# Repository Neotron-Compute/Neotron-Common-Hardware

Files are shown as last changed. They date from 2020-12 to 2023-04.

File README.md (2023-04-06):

# Neotron-Common-Hardware

Contains KiCad footprints and symbols shared across multiple Neotron projects. It also contains example schematics for circuits we expect to see on most Neotron boards.

## Components

### Audio Codec

* Texas Instruments TLV320AIC23B
  * I²S + I²C interface
  * Amplified 32mW headphone output and line out
  * Microphone in and line in
  * TSSOP-28 package (0.635mm pitch)
* Triple 3.5mm TRS jack (Kycon STX-4335-5BGP-S1)
  * Headphone Out (green)
  * Line In (blue)
  * Microphone In (pink)
* AC'97 Pin Header
  * Headphone Out
  * Microphone In
* Extra line-level output pin header (e.g. for additional RCA audio jacks - operates in addition to 3.5mm headphone jack output)
* Internal line-level input pin header (e.g. for CD-ROM audio - disabled when line-in 3.5mm jack in-use)

### Super VGA output

* 15-pin D-Sub VGA interface
* 18-bit (6-6-6) and 12-bit (4-4-4) RGB R2R DACs
  * Requires you to connect up a CPU that can generate digital parallel RGB video
* 3peak TPF133A or Texas Instruments THS7316 RGB video buffer
   * 36 MHz bandwidth - 1024x768@60Hz maximum
   * 6dB gain
   * Drives 75 ohm standard VGA interface
   * SOIC-8 package (1.27mm pitch)
* Texas Instruments TPD7S019 Sync/DDC level shifter and RGB EMC filter
   * SSOP-16 package (0.635mm pitch)

### RS232 Interface

* Tx, Rx, RTS and CTS signals
* 3.3V TTL on the MCU side
* Low-power ST ST3232C RS-232 level shifter (powered from single 3.3V rail)
* RS-232 signalling on a 9-pin D-Sub connector (or 10-pin IDC box header), wired DTE

### USB

* Four port USB 2.0 High Speed hub
* MaxLinear XR22404CG28 USB2.0 hub IC
  * SSOP-28 package (0.635mm pitch)
* Two USB 2.0 High Speed Type-A ports
* 8-pin PC case style USB pin-header (providing two USB 2.0 High Speed ports)
* Each port limited to 500mA with over-current protection

### Ethernet

* 10/100base-T Ethernet
* Microchip ENC424J600 Ethernet MAC/PHY with SPI connection to main CPU
  * TQFP-44 package (0.8mm pitch)
* Link and Activity LEDs

### Board Management Controller

Power-on Reset sequencing, soft shutdown, voltage monitoring and PS/2 interfacing is handled by a separate STM32F0 SoC.

* ST Micro STM32F0 (STM32F030K6T6) microcontroller
  * 32-bit Arm Cortex-M0+ Core
  * 3.3V I/O (5V tolerant)
  * 32 KiB Flash
  * 4 KiB SRAM
  * LQFP-32 package (0.8mm pitch)
* Controls two PS/2 ports
* Monitors 5V and 3.3V rails
* Controls system reset, soft-on and soft-off for main CPU
* Can the main 5V regulator on and off
* Runs from 3.3V stand-by regulator
* SPI interface (with dedicated IRQ line) with main CPU
* Secondary I²C bus which can be controlled over SPI

| Pin  | Name | Signal | Function |
| :--- | :--- | :--- | :--- |
| 02 | PF0  | nBUTTON_PWR | Power Button Input (active low) |
| 03 | PF1  | nBUTTON_RST | Reset Button Input (active low) |
| 06 | PA0  | MON_3V3 | 3.3V rail monitor Input (1.65V nominal) |
| 07 | PA1  | MON_5V | 5.0V rail monitor Input (1.65V nominal) |
| 08 | PA2  | nSYS_RESET  | Reset Output to reset the rest of the system |
| 09 | PA3  | DC_ON | PSU Enable Output |
| 10 | PA4  | SPI1_NSS | SPI Chip Select Input (active low) |
| 11 | PA5  | SPI1_SCK | SPI Clock Input |
| 12 | PA6  | SPI1_CIPO | SPI Data Output |
| 13 | PA7  | SPI1_COPI | SPI Data Input |
| 14 | PB0  | LED0 | PWM output for first Status LED |
| 15 | PB1  | LED1 | PWM output for second Status LED |
| 18 | PA8  | nHOST_IRQ | Interrupt Output to the Host (active low) |
| 19 | PA9  | USART1_TX | UART Transmit Output |
| 20 | PA10 | USART1_RX | UART Receive Input |
| 21 | PA11 | USART1_CTS  | UART Clear-to-Send Output |
| 22 | PA12 | USART1_RTS  | UART Ready-to-Receive Input |
| 23 | PA13 | SWDIO | SWD Progamming Data Input |
| 24 | PA14 | SWCLK | SWD Programming Clock Input |
| 25 | PA15 | PS2_CLK0 | Keyboard Clock Input |
| 26 | PB3  | PS2_CLK1 | Mouse Clock Input |
| 27 | PB4  | PS2_DAT0 | Keyboard Data Input |
| 28 | PB5  | PS2_DAT1 | Mouse Data Input |
| 29 | PB6  | I2C1_SCL | I²C Clock |
| 30 | PB7  | I2C1_SDA | I²C Data |

Note that in the above table, the UART signals labelled from the point of view of the BMC chip (i.e. UART_RX is an input to the BMC). The PS/2 signals are 5V open-collector, and so must be on 5V tolerant pins. Everything else runs at 3.3V.

This design should also be pin-compatible with the following SoCs (although the software may need recompiling with a different _Peripheral Access Crate_):

* STM32F031K6Tx
* STM32F042K4Tx
* STM32F042K6Tx
* STM32F051K4Tx
* STM32F051K6Tx
* STM32F051K8Tx
* STM32L071KBTx
* STM32L071KZTx
* STM32L072KZTx
* STM32L081KZTx
* STM32L082KZTx

Note that not all STM32 pins are 5V-tolerant, and as noted above, the PS/2 pins are 5V open-collector. You must therefore ensure that whichever part you pick has 5V-tolerant pins (marked `FT` or `FTt` in the datasheet) for the PS/2 signals. All of the parts above _should_ be OK, but they haven't been tested. Let us know if you try one!

### PS/2 Keyboard and Mouse

* Kycon two-port stacked 6-pin DIN sockets (Kycon KMDGX-6S/6S-S4N)
* Controlled via Board Management Controller

### Power Supply

* Unregulated 12V (8V to 28V) input fused with a PTC at 2A
* 3A 5.0V main regulator (DC-DC switch-mode regulator module)
  * Morsun K7805-3AR3
* 30mA 3.3V stand-by regulator (a micropower linear regulator)
* 1A 3.3V regulator (a high-power 1117 type linear regulator)
* Controlled by the Board Management Controller

### CPU Socket

The CPU can either be designed to solder direct to your particular motherboard design, or it can be fitted to a second PCB 'CPU card' which plugs into a socket on the motherboard. We have designed a special 80-pin socket pinout, which provides all the signals for required for the standard peripherals available in this design.

The socket is basically two 2x20 pin headers, placed 130 mil apart. This should give enough space to fit even a TQFP-176 microcontroller and some TSOP-54 SDRAM.

The pins are labelled in row.column fashion, i.e. 1.1 is top left, 1.20 is top right and 4.20 is bottom right.

```
 +----- Pin 1.1
 |
 v
+---------------------------------------+
|o o o o o o o o o o o o o o o o o o o o|
|o o o o o o o o o o o o o o o o o o o o|
+---------------------------------------+

+---------------------------------------+
|o o o o o o o o o o o o o o o o o o o o|
|o o o o o o o o o o o o o o o o o o o o|
+---------------------------------------+
                                       ^
                                       |
                         Pin 4.20 -----+
```

| Pin  | Function |
| :--- | :--- |
| 1.1  | VGA_RED5 |
| 1.2  | VGA_RED4 |
| 1.3  | VGA_RED3 |
| 1.4  | VGA_RED2 |
| 1.5  | VGA_RED1 |
| 1.6  | VGA_RED0 |
| 1.7  | VGA_GREEN5 |
| 1.8  | VGA_GREEN4 |
| 1.9  | VGA_GREEN3 |
| 1.10 | VGA_GREEN2 |
| 1.11 | VGA_GREEN1 |
| 1.12 | VGA_GREEN0 |
| 1.13 | VGA_BLUE5 |
| 1.14 | VGA_BLUE4 |
| 1.15 | VGA_BLUE3 |
| 1.16 | VGA_BLUE2 |
| 1.17 | VGA_BLUE1 |
| 1.18 | VGA_BLUE0 |
| 1.19 | VGA_HSYNC |
| 1.20 | VGA_VSYNC |
| 2.1  | VGA_DDC_SDA |
| 2.2  | VGA_DDC_SCL |
| 2.3  | UART_RX |
| 2.4  | UART_TX |
| 2.7  | 3V3 |
| 2.8  | 3V3 |
| 2.9  | 3V3 |
| 2.10 | GND |
| 2.11 | GND |
| 2.12 | GND |
| 2.13 | AUDIO_BCLK_TO_CODEC  |
| 2.14 | AUDIO_DAT_TO_CODEC |
| 2.15 | AUDIO_LR_TO_CODEC |
| 2.16 | AUDIO_DAT_FROM_CODEC |
| 2.17 | AUDIO_LR_FROM_CODEC  |
| 2.18 | USB_EN |
| 2.19 | USB_D- |
| 2.20 | USB_D+ |
| 3.1  | I2C_SDA |
| 3.2  | I2C_SCL |
| 3.3  | UART_CTS |
| 3.4  | UART_RTS |
| 3.7  | GND |
| 3.8  | GND |
| 3.9  | GND |
| 3.10 | 5V |
| 3.11 | 5V |
| 3.12 | 5V |
| 3.13 | ~SPI_CS7 |
| 3.14 | ~SPI_CS6 |
| 3.15 | ~SPI_CS5 |
| 3.16 | ~SPI_CS4 |
| 3.17 | ~SPI_CS3 |
| 3.18 | ~SPI_CS2 |
| 3.19 | ~SPI_CS1 |
| 3.20 | ~SPI_CS0 |
| 4.1  | ~SDMMC_CARD_DETECT |
| 4.2  | ~SDMMC_WRITE_PROT |
| 4.3  | SDMMC_DAT2 |
| 4.4  | SDMMC_DAT3 |
| 4.5  | SDMMC_CMD |
| 4.6  | SDMMC_CLK |
| 4.7  | SDMMC_DAT0 |
| 4.8  | SDMMC_DAT1 |
| 4.9  | SPI_COPI |
| 4.10 | SPI_CIPO |
| 4.11 | SPI_CLK |
| 4.12 | ~RESET |
| 4.13 | ~IRQ7 |
| 4.14 | ~IRQ6 |
| 4.15 | ~IRQ5 |
| 4.16 | ~IRQ4 |
| 4.17 | ~IRQ3 |
| 4.18 | ~IRQ2 |
| 4.19 | ~IRQ1 |
| 4.20 | ~IRQ0 |

## Expansion

The (up-to) seven expansion sockets allow you to add on I²C or SPI based devices at a later date. Each provides a single chip-select and a single IRQ line - the motherboard design should ensure each socket gets a unique signal for each of these. Each expansion device should also contain a AT24C256 or similar EEPROM device. To allow these EEPROM devices to be scanned, each slot also contains three `EEPROM_ADDRESS` pins, tied to Vcc or GND in a unique combination. These should be connected through to the EEPROM address lines on your AT24C256, thus ensuring that each expansion card has its EEPROM at a unique address - 0x50 on Slot 0 through to a maximum possible 0x57 for Slot 7. Where your board has on-board devices, you should fit an AT24C256 EEPROM for each device so that the on-board devices can be discovered, exactly as if they were on an expansion card.

The expansion slot is a simple 2x10 header. We suggest the use of a TE card-edge connector, but you could equally use two 1x10 pin-headers if desired.

The pin functions are:

```
     SPI_COPI   1    2   GND
     SPI_CIPO   3    4   GND
      SPI_CLK   5    6   GND
      ~SPI_CS   7    8   ~IRQ
      I2C_SDA   9   10   I2C_SCL
 EEPROM_ADDR0   11  12   EEPROM_ADDR1
 EEPROM_ADDR2   13  14   ~RESET
           5V   15  16   5V
          3V3   17  18   3V3
          GND   19  20   GND
```

There are symbols and footprints for the mainboard side (card-edge socket, supplies power), and the expansion card side (golden-finger edge connector, receives power).

## Expansion Ideas

Why not design and build your own expansion card? You could try designing:

* A dual Atari/SEGA 9-pin Joypad Interface
* A Mikro Eletronika Click adaptor, allow many of the range of [Click boards](https://www.mikroe.com/click) to be fitted
* A Wi-Fi/Bluetooth card, using an Espressif ESP32
* A second processor card - perhaps with a RISC-V microcontroller, or classic Zilog Z80
* An OPL2 or OPL3 based FM synthesiser card
* An ISA adaptor card (taking an ISA card at right-angles, i.e. parallel to the base board) - a simple microcontroller should be able to bit-bang the ISA bus at 8 MHz and offer an SPI peripheral interface to the Neotron Expansion Slot
* An IDE interface card, allowing 40-pin IDE Hard Disk Drives and CD-ROM drives to be used - this will be quite similar to an ISA bus adaptor
* A floppy drive controller card - either using an eSPI Super I/O chip, or connecting a legacy ISA bus floppy controller as per the ISA adaptor
* A video card for a second monitor output, perhaps based on the CPLD used in the [VGAtonic](https://hackaday.io/project/6309-vga-graphics-over-spi-and-serial-vgatonic)

## Changelog

See [CHANGELOG.md](./CHANGELOG.md) for a list of detailed changes.

## Git Setup

We recommend you have the following Git config set:

```
$ git config --global filter.kicad_project.clean "sed -E 's/^update=.*$/update=Date/'"
$ git config --global filter.kicad_project.smudge cat
$ git config --global filter.kicad_sch.clean "sed -E 's/#(PWR|FLG)[0-9]+/#\1?/'"
$ git config --global filter.kicad_sch.smudge cat
```

See https://jnavila.github.io/plotkicadsch/ for details.

## Automated Builds

This project treats a PCB like embedded firmware:

* The *source files* are the KiCAD 7 files (in `./Kicad`)
* The *compiler* is KiCAD 7, plus various automation plug-ins (like KiBom)
* The *build system* is [KiBot](https://github.com/INTI-CMNB/KiBot)
* The *build outputs* are PDF versions of the schematic and the PCB, plus various zipped Gerber and Drill files.

We do not check *build outputs* into this repository - *ever*. Instead, we run a Github Action which uses KiBot to generate our outputs. On a regular Pull Request, the *build outputs* are stored as *artefacts* against the particular Github Action run. When a new version is tagged, the *build outputs* are stored as files against a [Github Release](https://github.com/Neotron-Compute/Neotron-Common-Hardware/releases).

Of course, the PCB in this project isn't useful by itself - it's a starting point for your project. You should probably include this repo as a Git Submodule, and add the symbol library and footprint library to your own KiCAD project.

You can build locally using the KiBot docker container:

```console
~/Neotron-Common-Hardware $ docker run --rm -ti -v $(pwd):/work setsoft/kicad_auto:ki7
root@12345678:/# cd /work/Kicad
root@12345678:/work/Kicad# kibot -c docs.kibot.yml -e Neotron-Common-Hardware.kicad_sch -b Neotron-Common-Hardware.kicad_pcb -d docs
```

This will build everything and put it in the `./Kicad/docs` directory.

## Licence

This schematic and PCB design is Copyright (c) The Neotron Developers.



This work is licensed under a [Creative Commons Attribution-ShareAlike 4.0 International License](http://creativecommons.org/licenses/by-sa/4.0/).

## Contribution Agreement

Unless you explicitly state otherwise, any contribution intentionally submitted for inclusion in the work by you, as defined in the Apache-2.0 license, shall be licensed as above, without any additional terms or conditions.

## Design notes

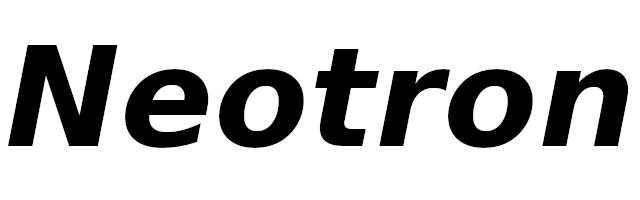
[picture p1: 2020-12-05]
neotron.png

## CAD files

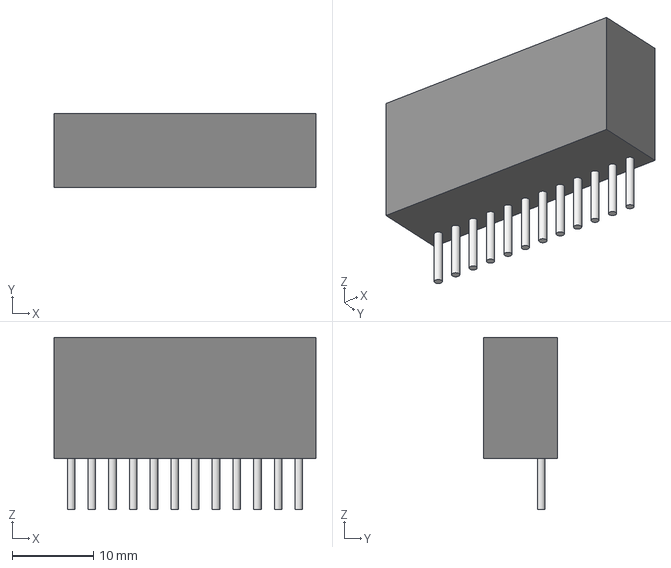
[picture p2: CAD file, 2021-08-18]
Kicad/Models/K78XX-3AR3.step
32.2 x 9.04 x 21.2 mm

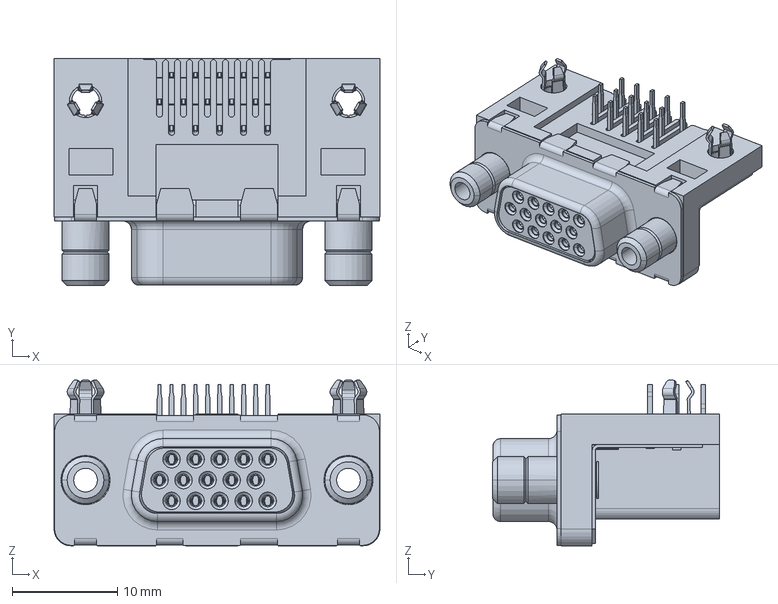
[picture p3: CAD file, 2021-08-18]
Kicad/Models/ICD15S13E4GV00LFc.stp
31.0 x 21.6 x 15.8 mm

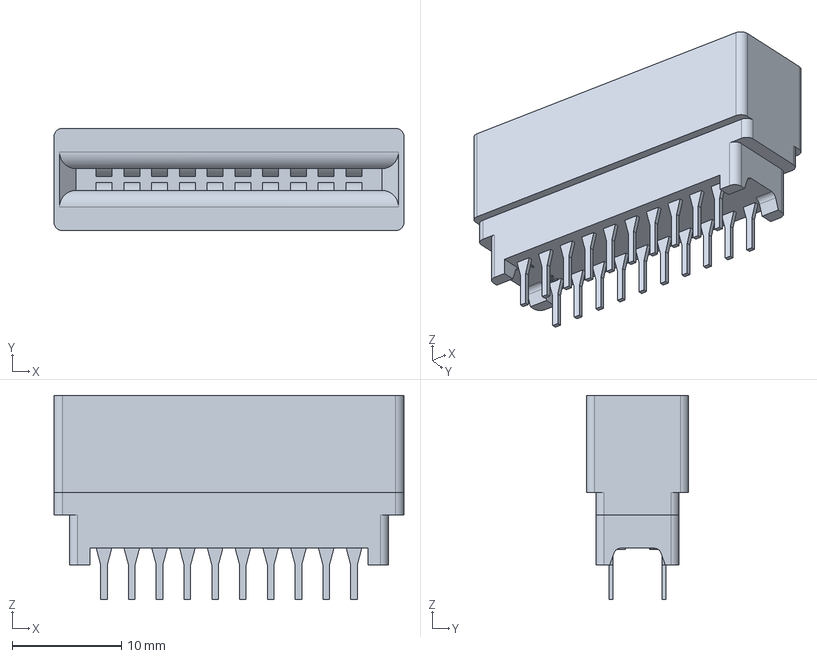
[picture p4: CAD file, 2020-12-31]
Kicad/Models/5-5530843-0--3DModel-STEP-1.STEP
32.0 x 9.35 x 18.7 mm

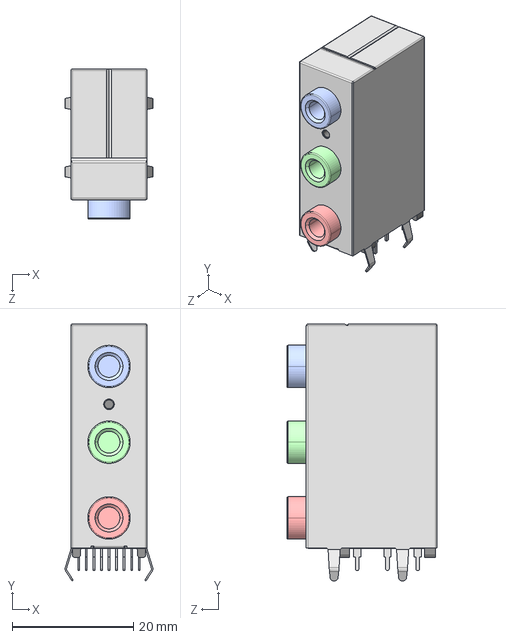
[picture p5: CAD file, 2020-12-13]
Kicad/Models/STX-4335-5BGP-S1_rB3.STEP
14.5 x 42.4 x 24.8 mm

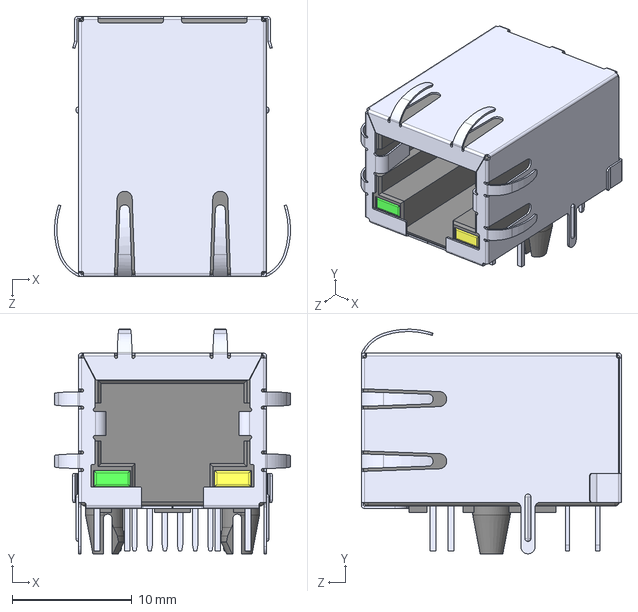
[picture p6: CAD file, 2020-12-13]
Kicad/Models/RJMG1BD3B8K1ANR--3DModel-STEP-56544.STEP
19.7 x 18.8 x 21.8 mm

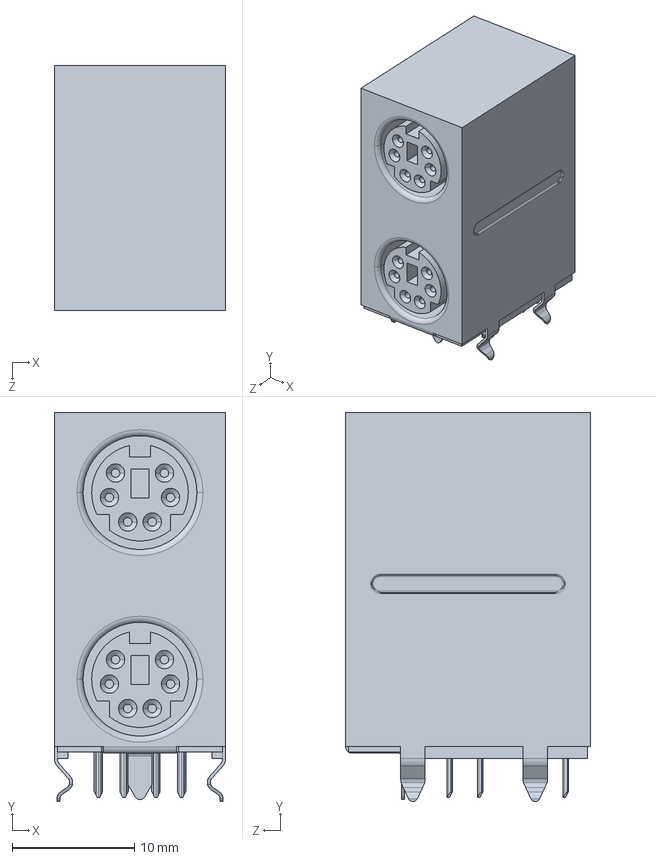
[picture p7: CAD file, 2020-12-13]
Kicad/Models/KMDGX-6S-6S-S4N_rB8.STEP
14.0 x 31.8 x 20.0 mm

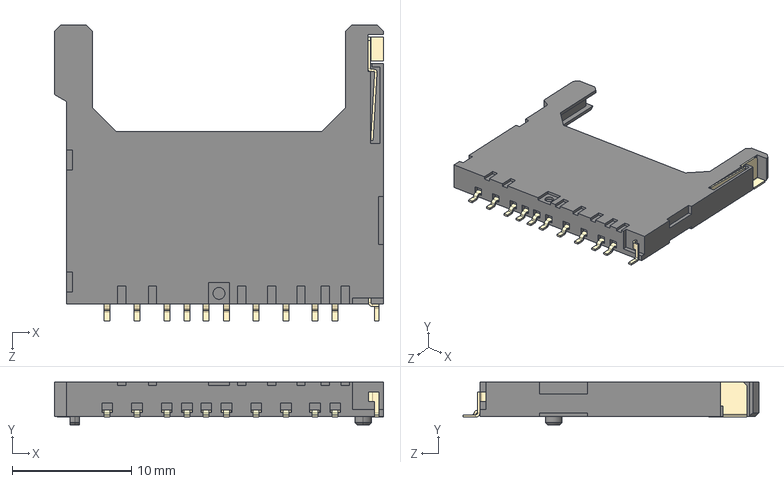
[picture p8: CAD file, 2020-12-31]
Kicad/Models/145638009211859+--3DModel-STEP-56544.STEP
27.6 x 3.60 x 24.8 mm

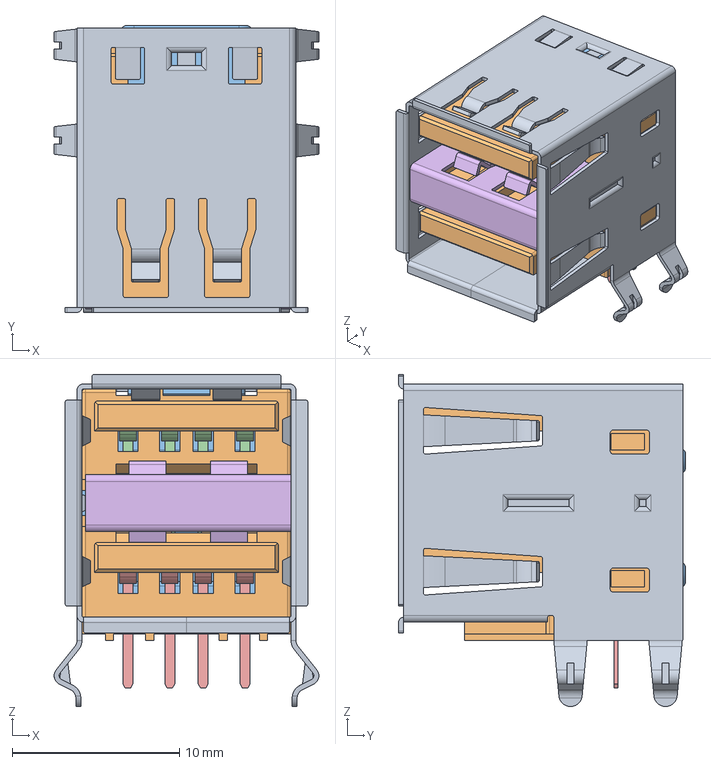
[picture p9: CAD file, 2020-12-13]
Kicad/Models/61400826021.stp
15.8 x 17.1 x 19.8 mm

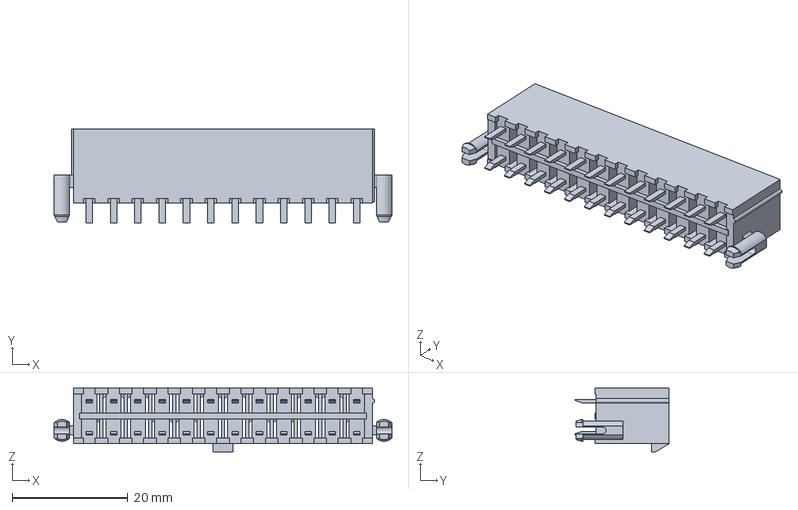
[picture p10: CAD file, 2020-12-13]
Kicad/Models/039299246.stp
58.4 x 16.3 x 11.0 mm

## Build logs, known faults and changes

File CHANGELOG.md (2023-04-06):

# Changelog

## Unreleased Changes

* None

## v2.0.0

* Updated to KiCAD 7
* Reduced size of holes for PSU pins from 1.2mm to 1.02mm

## v1.0.0

* Updated to KiCAD 6
* Backported changes from Neotron Pico
  * Split microphone audio / bias
  * DNF components now not shown on iBOM
  * External LED drive is 5V 20mA
  * Two PSU control BJTs are now surface mount
  * Use 200mA Holtek HT7533-1 stand-by regulator
  * Added internal 12V input header
  * K7805-3AR3 control pin is protected with a zener (allows higher input voltages)
  * HDD LED is driven from I/O mux, not BMC
  * Replaced 12 MHz Crystal with JLCPCB basic part
  * Replaced SD Card with Amphenol part
  * Replaced decoupling with single 10uF
  * Added PC speaker output
  * Changed K7805-3AR3 to have ceramic output cap
  * Increased VGA DAC current
  * Replace 74HC245 with 74HC138, plus five LEDS for the now spare pins
  * Adds 6mm switches for power and reset
  * Added internal 5V/3.3V output header
  * Reverse polarity protection on the input

## v0.12.0

* Add a second TPF133A but with RGB pins swapped (the channels are identical).

## v0.11.0

* Added Expansion Edge connector for making expansion cards.

## v0.10.0

* SYS_RESET is pulled down.
* 5V PSU's `Ctrl` input is now controlled with PNP/NPN transistor pair.
* Added extra explanatory text to BMC page
* Added not on audio sheet about split grounds.

## v0.9.3

* Remove audio split ground by joining GND and GNDA

## v0.9.2

* Change Audio LR and BCLK pins to be bi-directional
* Also renamed all Audio pins for clarity

## v0.9.1

* Swapped BUTTON_PWR and SYS_RESET to avoid DRC issue
* Split PSU and BMC into two separate sheets
* Swapped some pins on the STM32 to make it compatible with more alternatives

## v0.9.0

* Changed STM32 pinout to add 4-wire UART and move to SPI bus
* Added some Mouser part numbers
* Marked resistors as 1% where not specified

## v0.8.0

* Updated some 5V0 caps from 10V to 16V
* README updates

## v0.7.0

* Replaced STM32F0 TSSOP with LQFP-32
  * Has 0.8mm pitch (instead of 0.65mm) so should be easier to solder
* Replaced most of the big electrolytics with 0805 MLCC
  * Takes up less board space

## v0.6.0

* Added 3D model for USB header
* Changed main input Inductor to horizontal footprint
* Created footprint for Mornsun DC/DC PSU
* Added header for case power LED
* Changed BMC debug header to standard part

## v0.5.0

* Swap BMC from NXP KE04Z to ST STM32F0

## v0.4.0

* Added missing part numbers.

## v0.3.1

* Fix ERC error when SPI CIPO pins joined together.

## v0.3.0

* Added R2R DAC

## v0.2.0

* Added RTC sheet

## v0.1.0

First WIP draft release.

* Sub-modules added
* Connector fit in ATX IO area tested
* Audio Codec Sheet
* SD Card Sheet
* Ethernet Sheet
* Video Sheet
* Serial Sheet
* CPU Socket defined
* Expansion Socket defined

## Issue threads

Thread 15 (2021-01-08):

Create specific debug header

thejpster, 2021-01-08:
The STM32F0 currently has a combination of test points and jumpers. We should just use a 2x5 2.54mm pin header. and give the user instructions on where to fit the jumpers.

Closed 2021-01-08.

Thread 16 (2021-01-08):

Add LED header

thejpster, 2021-01-08:
The status LED that tells us the system is up and running is currently a 5mm LED. We should add a second 1k resistor and a 2.54mm pin header for a case LED. This should be located near the reset and power button headers.

thejpster, 2021-01-08:
Closed by #24

Closed 2021-01-08.

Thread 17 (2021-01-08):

Mornsun PSU needs its own footprint

thejpster, 2021-01-08:
The pins on the Mornsun PSU appear to be 3mm pitch not 2.54mm pitch. We should just draw ourselves a nice footprint for the PSU.

thejpster, 2021-01-08:
No, it its 2.54mm after all. I was comparing a physical unit with a 2.54mm pin header I had lying around - except it happened to be a 2mm pin header!

Anyway, made a new footprint with a courtyard and cleaned up the symbol pins.

Closed 2021-01-08.

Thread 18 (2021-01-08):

Inductor won't stand up

thejpster, 2021-01-08:
The legs on the big 22uH inductor are too short to allow it to stand vertically. We should swap to a horizontal footprint, or change the part.

Closed 2021-01-08.

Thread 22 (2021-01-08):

Consider DIN 41612 connectors

thejpster, 2021-01-08:
Edge connectors are inexpensive, but require your expansion cards to be hard gold if you want any kind of durability. This really puts up the price of the expansion PCBs.

Nubus used DIN 41612 connectors, which are rated for 50 to 500 insertions. Plus they look a) cool b) authentically retro.

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

thejpster, 2021-01-16:
This 48 pin, 3 row, vertical socket is nice:

https://www.te.com/commerce/DocumentDelivery/DDEController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

https://www.digikey.co.uk/product-detail/en/te-connectivity-amp-connectors/5536397-5/A113959-ND/3466293

Costs £2.29 in small quantities. I do think the baseboard should have sockets because it supplies power. The Raspberry Pi uses a pin header rather than a socket and I think it's too easy to touch 5V and GND together.

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

thejpster, 2021-01-16:
This right angle socket at £2.90 is the matching part.

https://www.digikey.co.uk/product-detail/en/te-connectivity-amp-connectors/5650478-5/A32298-ND/811088

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

thejpster, 2021-01-16:
If you just use "normal" 0.1" headers and sockets, it's much cheaper.

https://www.digikey.co.uk/product-detail/en/sullins-connector-solutions/SFH11-PBPC-D08-ST-BK/S9196-ND/1990089

68p in small qtys.

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

Closed 2021-06-18.

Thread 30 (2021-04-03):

CODEC LR and BCLK pins should be bi-dir

thejpster, 2021-04-03:
The BCLK pin and the two LRCLK pins are inputs in so-called _slave_ mode and outputs in so-called _master_ mode. The sheet should mark them as bi-dir.

thejpster, 2021-04-04:
Fixed in 6d5f5d06e4

Closed 2021-04-06.

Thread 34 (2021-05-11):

Switch to Octopart CPL

thejpster, 2021-05-11:
Octopart has a "common parts library", which part numbers for generic items (like resistors, capacitors, etc). In the Octopart BOM tool these will then map to a manufacturer specific equivalent.

https://octopart.com/common-parts-library

We should use parts from the CPL in this repo.

Closed 2021-06-18.

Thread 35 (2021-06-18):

Backport changes from Neotron Pico

thejpster, 2021-06-18:
Neotron Pico had to copy-paste the schematics due to Kicad issues.

We should pick up the changes and bring them back here.

Closed 2021-06-18.

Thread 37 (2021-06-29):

Expansion Card

thejpster, 2021-06-29:
We need a demonstration expansion card. Something with the gold fingers and holes for an expansion card bracket.

For brackets see:

* https://www.keyelco.com/category.cfm/Brackets-Computer-Mounting/Computer-Brackets-PC-Card/id/427
* https://www.aliexpress.com/item/32974251930.html
* https://www.mouser.co.uk/Electromechanical/Hardware/Circuit-Board-Hardware-PCB/_/N-5g2e

thejpster, 2021-08-20:
See https://github.com/Neotron-Compute/Neotron-Expansion-Template

Closed 2021-08-20.

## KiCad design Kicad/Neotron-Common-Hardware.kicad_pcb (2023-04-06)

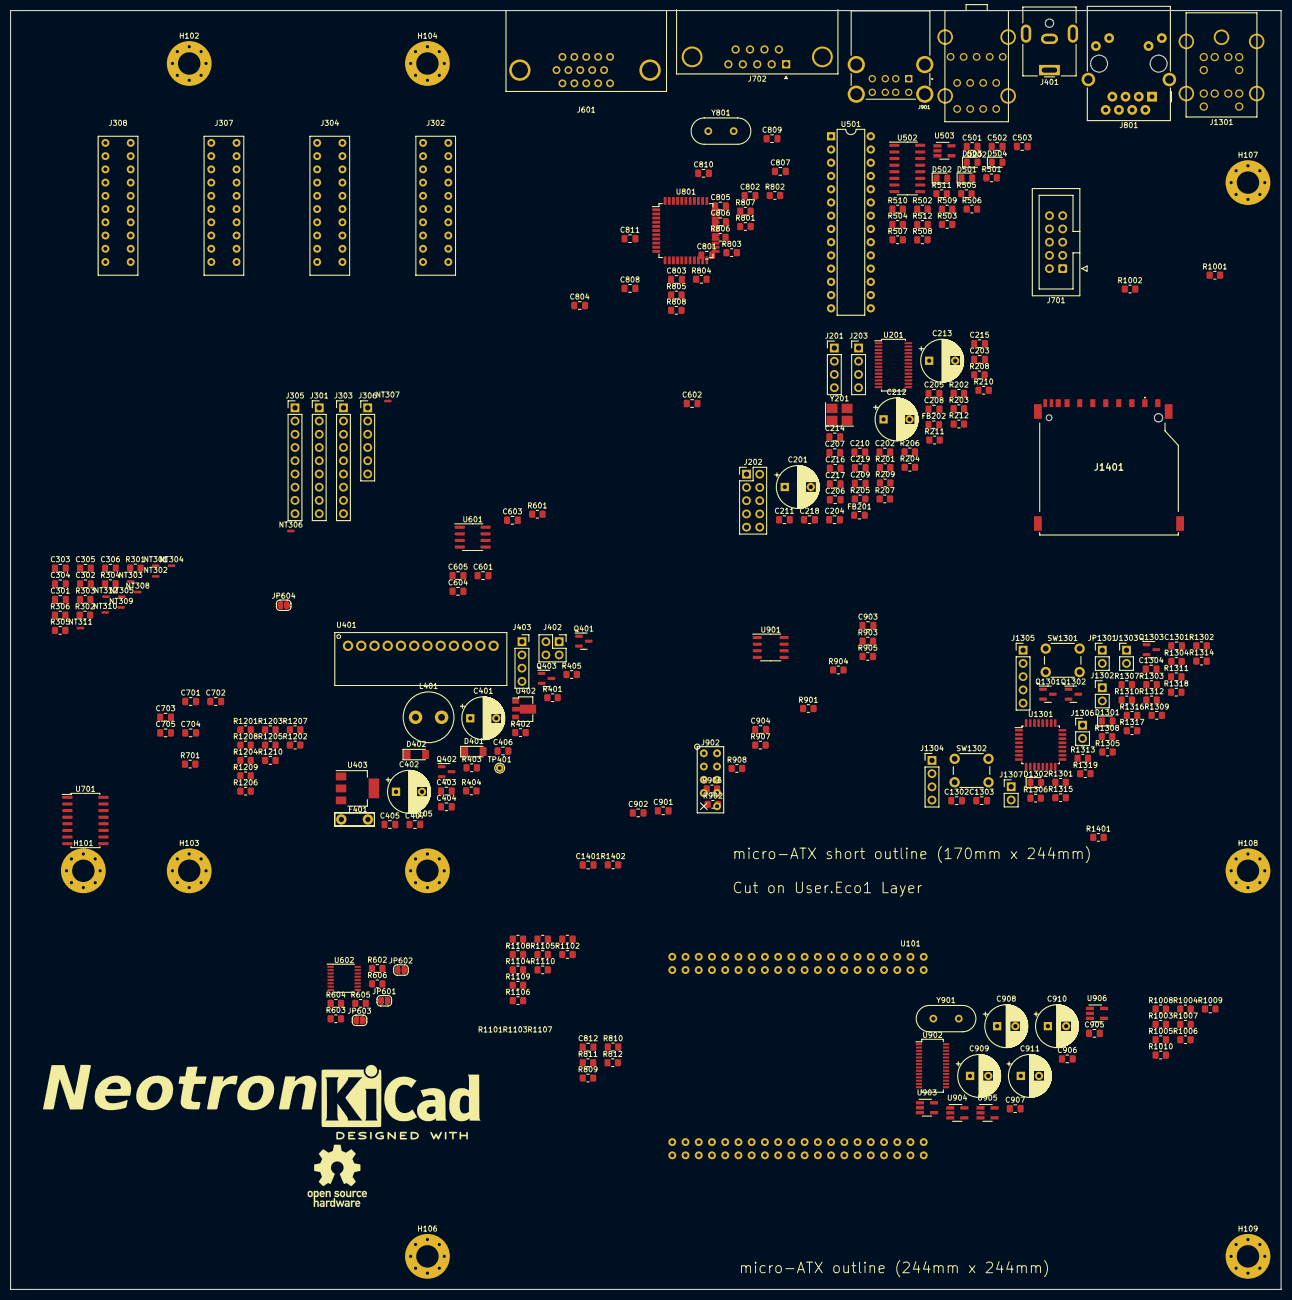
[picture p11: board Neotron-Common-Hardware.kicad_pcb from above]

Board: 4 copper layers, 243.8 x 245.5 mm, 287 parts (0 on the bottom side), 218 nets, no tracks yet.

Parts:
C201, C212, C213, C401, C402: 100u; CP_Radial_D8.0mm_P5.00mm
C202, C205, C206, C207, C209, C404, C405, C502, C503, C601, C603, C604, C605, C808, C1301, C1302, C1304, C1401: 10u; C_0805_2012Metric_Pad1.18x1.45mm_HandSolder
C203, C204: 22p; C_0805_2012Metric_Pad1.18x1.45mm_HandSolder
C208, C701, C702, C703, C704, C705, C801, C802, C803, C804, C805, C902, C904, C906: 100n; C_0805_2012Metric_Pad1.18x1.45mm_HandSolder
C210, C211, C214, C215, C218: 1u; C_0805_2012Metric_Pad1.18x1.45mm_HandSolder
C216, C217, C219: 47p; C_0805_2012Metric_Pad1.18x1.45mm_HandSolder
C301, C302, C303, C304, C305, C306, C501: DNF; C_0805_2012Metric_Pad1.18x1.45mm_HandSolder
C403, C406, C407: 22u; C_0805_2012Metric_Pad1.18x1.45mm_HandSolder
C602: 220n; C_0805_2012Metric_Pad1.18x1.45mm_HandSolder
C806, C807: 1n; C_0805_2012Metric_Pad1.18x1.45mm_HandSolder
C809, C810, C901, C903: 12p; C_0805_2012Metric_Pad1.18x1.45mm_HandSolder
C811, C812, C1303: 10n; C_0805_2012Metric_Pad1.18x1.45mm_HandSolder
C905, C907: 4.7u; C_0805_2012Metric_Pad1.18x1.45mm_HandSolder
C908, C909, C910, C911: 120u; CP_Radial_D8.0mm_P3.50mm
D401, D402: ZMM5V6; D_MiniMELF
D501, D502, D503, D504, D1301, D1302: LED; LED_0805_2012Metric_Pad1.15x1.40mm_HandSolder
F401: 32V 2A PTC; Bel Fuse 0ZRS0200FF
FB201, FB202: 330R@100MHz; L_0805_2012Metric_Pad1.15x1.40mm_HandSolder
H101, H102, H103, H104, H105, H106, H107, H108, H109: MountingHole_Pad; MountingHole_4.3mm_M4_Pad_Via
J201, J203, J1304: Conn_01x04; PinHeader_1x04_P2.54mm_Vertical
J202: Conn_02x05; PinHeader_2x05_P2.54mm_Vertical
J301, J303, J305: Conn_01x09; PinHeader_1x09_P2.54mm_Vertical
J302, J304, J307, J308: Neotron-Expansion-Slot
J306: Conn_01x06; PinHeader_1x06_P2.54mm_Vertical
J401: Jack 2.1mm 6.3mm; BarrelJack_CUI_PJ-063AH_Horizontal
J402: Conn_02x02S; PinSocket_2x02_P2.54mm_Vertical
J403: Conn_01x04S; PinSocket_1x04_P2.54mm_Vertical
J601: DE15HD; Amphenol_ICD15S13E4GV00LF
J701: Conn_02x05; IDC-Header_2x05_P2.54mm_Vertical
J702: DB9_Male_MountingHoles; DSUB-9_Male_Horizontal_P2.77x2.84mm_EdgePinOffset7.70mm_Hou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
J801: RJ45 MagJack; RJ45_Amphenol_RJMG1BD3B8K1ANR
J901: USB Ports External; CUI_UJ2-ADH-1-TH
J902: USB Ports Internal; USB_Header
J1301: Double-mini-DIN-6; Double_mini-DIN_6
J1302, J1303, J1306, J1307: Conn_01x02; PinHeader_1x02_P2.54mm_Vertical
J1305: Conn_01x05; PinHeader_1x05_P2.54mm_Vertical
J1401: SD_Card; Amphenol_GSD090012SEU
JP601, JP602, JP603, JP604: Bridge; SolderJumper-2_P1.3mm_Open_RoundedPad1.0x1.5mm
JP1301: Jumper; PinHeader_1x02_P2.54mm_Vertical
L401: 22uH; L_Radial_D9.5mm_P5.00mm_Fastron_07HVP
LOGO101: Neotron Logo; logo
LOGO102: Kicad Logo; KiCad-Logo2_12mm_SilkScreen
LOGO103: OSHW Logo; OSHW-Logo_11.4x12mm_SilkScreen
NT301, NT302, NT303, NT304, NT305, NT306, NT307, NT308, NT309, NT310, NT311, NT312: NetTie_2; NetTie-2_SMD_Pad0.5mm
Q401, Q1301: SS8050; SOT-23
Q402: AO3401A; SOT-23
Q403: SS8550; SOT-23
Q1302, Q1303: 2N7002; SOT-23
R201, R202, R204, R301, R302, R303, R304, R305, R306, R501: 0R; R_0805_2012Metric_Pad1.20x1.40mm_HandSolder
R203, R605, R606, R1001, R1002, R1004, R1006, R1008, R1101, R1102, R1104, R1106, R1108, R1201, R1202, R1204, R1206, R1208: 2k; R_0805_2012Metric_Pad1.20x1.40mm_HandSolder
R205, R206, R208, R209, R801: 100k; R_0805_2012Metric_Pad1.20x1.40mm_HandSolder
R207, R210, R211, R212: 4k7; R_0805_2012Metric_Pad1.20x1.40mm_HandSolder
R401, R402, R403, R404, R502, R504, R506, R508, R510, R511, R512, R901, R902, R903, R904, R905, R907, R908, R1305, R1308, R1314, R1315, R1317, R1318, R1319, R1401, R1402: 10k; R_0805_2012Metric_Pad1.20x1.40mm_HandSolder
R405, R503, R505, R507, R509, R1003, R1005, R1007, R1009, R1103, R1105, R1107, R1109, R1203, R1205, R1207, R1209, R1301, R1302, R1303, R1304, R1306, R1309, R1312: 1k; R_0805_2012Metric_Pad1.20x1.40mm_HandSolder
R601, R602, R603: 75; R_0805_2012Metric_Pad1.20x1.40mm_HandSolder
R604, R701, R812: DNF; R_0805_2012Metric_Pad1.20x1.40mm_HandSolder
R802: 12k4; R_0805_2012Metric_Pad1.20x1.40mm_HandSolder
R803: 1M; R_0805_2012Metric_Pad1.20x1.40mm_HandSolder
R804, R805, R806, R807: 49R9; R_0805_2012Metric_Pad1.20x1.40mm_HandSolder
R808, R809: 10R; R_0805_2012Metric_Pad1.20x1.40mm_HandSolder
R810, R811: 180R; R_0805_2012Metric_Pad1.20x1.40mm_HandSolder
R906: 2k7; R_0805_2012Metric_Pad1.20x1.40mm_HandSolder
R1010, R1110, R1210, R1310, R1311, R1313, R1316: 300; R_0805_2012Metric_Pad1.20x1.40mm_HandSolder
R1307: 33R; R_0805_2012Metric_Pad1.20x1.40mm_HandSolder
SW1301, SW1302: SW_Push; SW_PUSH_6mm
TP401: PTH; TestPoint_THTPad_D1.5mm_Drill0.7mm
U101: Neotron-CPU; Neotron_CPU_Socket
U201: TLV320AIC23BPW; TSSOP-28_4.4x9.7mm_P0.65mm
U202: STX-4335-5BGP-S1
U401: DC-DC Module; K78xx-3AR3
U402: HT75xx-1-SOT89; SOT-89-3
U403: AMS1117-3.3; SOT-223-3_TabPin2
U501: MCP23S17_SP; DIP-28_W7.62mm
U502: 74HC138; SOIC-16_3.9x9.9mm_P1.27mm
U503: 74AHC1G04; SOT-23-5_HandSoldering
U601: THS7316; SOIC-8_3.9x4.9mm_P1.27mm
U602: TPD7S019; SSOP-16_3.9x4.9mm_P0.635mm
U701: ST3232CDR; SO-16_5.3x10.2mm_P1.27mm
U801: ENC424J600; TQFP-44_10x10mm_P0.8mm
U901: AP2501; SO-8_3.9x4.9mm_P1.27mm
U902: XR22404CG28; SSOP-28_3.9x9.9mm_P0.635mm
U903, U904, U905, U906: MIC2005A-2YM5; SOT-23-5_HandSoldering
U1301: STM32F030K6T6; LQFP-32_7x7mm_P0.8mm
Y201: 12M 20pF; Crystal_SMD_3225-4Pin_3.2x2.5mm_HandSoldering
Y801: 25M; Crystal_HC49-4H_Vertical
Y901: 12M; Crystal_HC49-4H_Vertical

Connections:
+3.3VP: C405.2, C1301.2, C1302.2, C1303.1, C1304.2, J1305.5, JP1301.1 (A), U402.3 (VOUT), U1301.1 (VDD), U1301.5 (VDDA), U1301.17 (VDD)
+3V3: C407.1, C502.1, C503.1, C601.1, C605.2, C701.2, C801.1, C802.1, C803.1, C804.1, C805.1, C806.1, C807.1, C1401.2, FB201.2, FB202.2, J301.8, J302.17 (3V3), J302.18 (3V3), J304.17 (3V3), J304.18 (3V3), J307.17 (3V3), J307.18 (3V3), J308.17 (3V3), J308.18 (3V3), J403.1, J1401.4 (VDD), NT302.2, NT304.2, NT305.2, NT309.2, NT310.2, NT312.2, R502.1, R503.1, R504.1, R505.1, R506.1, R507.1, R508.1, R509.1, R510.1, R512.1, R801.1, R804.2, R805.1, R806.2, R807.1, R808.1, R809.1, R901.1, R908.1, R1314.1, R1401.2, R1402.1, U101.2.7 (3V3), U101.2.8 (3V3), U101.2.9 (3V3), U403.2 (VO), U501.9 (VDD), U502.16 (VCC), U503.5 (VCC), U601.4 (Vcc), U602.7 (VCC_DDC), U701.16 (VCC), U801.4 (VDDOSC), U801.12 (VDDPLL), U801.15 (VDDRX), U801.18 (VDDTX), U801.44 (VDD)
+5V: C403.1, C406.1, C603.2, C604.2, C902.1, J202.7, J301.9, J302.15 (5V), J302.16 (5V), J304.15 (5V), J304.16 (5V), J307.15 (5V), J307.16 (5V), J308.15 (5V), J308.16 (5V), J403.4, J601.9, J1301.4, J1301.10, R605.1, R606.1, R1301.1, R1302.1, R1303.1, R1304.1, R1307.2, R1310.1, R1311.1, R1313.1, R1316.1, R1317.1, U101.3.10 (5V), U101.3.11 (5V), U101.3.12 (5V), U401.4 (Vo), U403.3 (VI), U602.1 (VCC_SYNC), U602.2 (VCC_VIDEO), U901.2 (IN), U901.3 (IN)
/Audio/3V3_ANALOG: C201.1, C205.1, C207.1, FB201.1, U201.8 (HPVDD), U201.14 (AVDD)
/Audio/3V3_DIGITAL: C202.1, C206.1, FB202.1, U201.1 (BVDD), U201.27 (DVDD)
/Audio/CDInL: J201.1, U202.34 (BlueTipOut)
/Audio/CDInR: J201.4, U202.33 (BlueRingOut)
/Audio/FrontHPL: C212.2, J202.9, R209.2
/Audio/FrontHPR: C213.2, J202.5, R206.1
/Audio/FrontMicAudio: J202.1, U202.4 (PinkTipOut)
/Audio/FrontMicBias: J202.3, U202.3 (PinkRingOut)
/Audio/LHpOut: C212.1, U201.9 (LHPOUT)
/Audio/LLineIn: C214.2, U201.20 (LLINEIN)
/Audio/LOut: C210.1, U201.12 (LOUT)
/Audio/LineOutL: C210.2, J203.1, R208.2
/Audio/LineOutR: C211.1, J203.4, R205.1
/Audio/MicBias: R203.2, U201.17 (MICBIAS)
/Audio/MicIn: R204.1, U201.18 (MICIN)
/Audio/RHpOut: C213.1, U201.10 (RHPOUT)
/Audio/RLineIn: C215.2, U201.19 (RLINEIN)
/Audio/ROut: C211.2, U201.13 (ROUT)
/Audio/RearHPL: J202.10, U202.25 (LimeTip)
/Audio/RearHPR: J202.6, U202.22 (LimeRing)
/Audio/RearInL: R211.1, U202.35 (BlueTip)
/Audio/RearInR: R212.1, U202.32 (BlueRing)
/Audio/RearMicAudio: C218.1, C219.2, U202.5 (PinkTip)
/Audio/RearMicBias: R203.1, U202.2 (PinkRing)
/Audio/VMID: C208.1, C209.1, U201.16 (VMID)
/Ethernet/~IRQ: R801.2, U801.24 (~INT/SPISEL)
/Expansion Slots/BMC/BUZZER: R1306.1, U1301.15 (PB1)
/Expansion Slots/BMC/LED0: D1302.2 (A), Q1303.1 (G), U1301.14 (PB0)
/Expansion Slots/BMC/MON_3V3: R1314.2, R1315.1, U1301.6 (PA0)
/Expansion Slots/BMC/MON_5V: R1318.2, R1319.1, U1301.7 (PA1)
/Expansion Slots/BMC/PS2_CLK0: J1301.5, R1301.2, U1301.25 (PA15)
/Expansion Slots/BMC/PS2_CLK1: J1301.11, R1303.2, U1301.26 (PB3)
/Expansion Slots/BMC/PS2_DAT0: J1301.1, R1302.2, U1301.27 (PB4)
/Expansion Slots/BMC/PS2_DAT1: J1301.7, R1304.2, U1301.28 (PB5)
/Expansion Slots/BMC/SPK_N: J1304.4, Q1301.3 (C)
/Expansion Slots/BMC/SPK_P: J1304.1, R1307.1
/Expansion Slots/BMC/SWCLK: J1305.4, U1301.24 (PA14)
/Expansion Slots/BMC/SWDIO: J1305.3, U1301.23 (PA13)
/Expansion Slots/BMC/~BMC_RST: J1305.2, U1301.4 (NRST)
/Expansion Slots/BMC/~BUTTON_PWR: J1302.1, SW1301.2, U1301.2 (PF0)
/Expansion Slots/BMC/~BUTTON_RST: J1303.1, SW1302.2, U1301.3 (PF1)
/Expansion Slots/DC_ON: R401.2, U1301.9 (PA3)
/Expansion Slots/FTDI_BRN: J306.2, U1301.22 (PA12)
/Expansion Slots/FTDI_GRN: J306.6, U1301.21 (PA11)
/Expansion Slots/FTDI_ORA: J306.4, U1301.20 (PA10)
/Expansion Slots/FTDI_YEL: J306.5, U1301.19 (PA9)
/Expansion Slots/HDD_LED: D1301.2 (A), Q1302.1 (G)
/Expansion Slots/PICO_SCL: J301.3, J302.10 (I2C_SCL), J304.10 (I2C_SCL), J307.10 (I2C_SCL), J308.10 (I2C_SCL)
/Expansion Slots/PICO_SDA: J301.2, J302.9 (I2C_SDA), J304.9 (I2C_SDA), J307.9 (I2C_SDA), J308.9 (I2C_SDA)
/Expansion Slots/SD Card/~WRITE_PROTECT: J1401.11 (WRITE_PROTECT), R1402.2
/Expansion Slots/SPI_CIPO: C301.1, C302.1, C303.1, C304.1, C305.1, C306.1, J301.7, R301.2, R302.2, R303.2, R304.2, R305.2, R306.2
/Expansion Slots/SPI_CIPO_S0: R302.1, U1301.12 (PA6)
/Expansion Slots/SPI_CIPO_S1: J1401.7 (DAT0), R306.1
/Expansion Slots/SPI_CIPO_S2: J302.3 (SPI_CIPO), R301.1
/Expansion Slots/SPI_CIPO_S3: J304.3 (SPI_CIPO), R303.1
/Expansion Slots/SPI_CIPO_S4: J307.3 (SPI_CIPO), R304.1
/Expansion Slots/SPI_CIPO_S5: J308.3 (SPI_CIPO), R305.1
/Expansion Slots/SPI_CLK: J301.5, J302.5 (SPI_CLK), J304.5 (SPI_CLK), J307.5 (SPI_CLK), J308.5 (SPI_CLK), J1401.5 (CLK), U1301.11 (PA5)
/Expansion Slots/SPI_COPI: J301.6, J302.1 (SPI_COPI), J304.1 (SPI_COPI), J307.1 (SPI_COPI), J308.1 (SPI_COPI), J1401.2 (CMD), U1301.13 (PA7)
/Expansion Slots/~CS0: J305.2, U502.15 (O0), U1301.10 (PA4)
/Expansion Slots/~CS1: J305.3, J1401.1 (CD/DAT3), U502.14 (O1)
/Expansion Slots/~CS2: J302.7 (~SPI_CS), J305.4, U502.13 (O2)
/Expansion Slots/~CS3: J304.7 (~SPI_CS), J305.5, U502.12 (O3)
/Expansion Slots/~CS4: J305.6, J307.7 (~SPI_CS), U502.11 (O4)
/Expansion Slots/~CS5: J305.7, J308.7 (~SPI_CS), U502.10 (O5)
/Expansion Slots/~CS6: J305.8, U502.9 (O6)
/Expansion Slots/~CS7: J305.9, U502.7 (O7)
/Expansion Slots/~IRQ0: J303.2, U501.1 (GPB0), U1301.18 (PA8)
/Expansion Slots/~IRQ1: J303.3, J1401.10 (CARD_DETECT), R1401.1, U501.2 (GPB1)
/Expansion Slots/~IRQ2: J302.8 (~IRQ), J303.4, U501.3 (GPB2)
/Expansion Slots/~IRQ3: J303.5, J304.8 (~IRQ), U501.4 (GPB3)
/Expansion Slots/~IRQ4: J303.6, J307.8 (~IRQ), U501.5 (GPB4)
/Expansion Slots/~IRQ5: J303.7, J308.8 (~IRQ), U501.6 (GPB5)
/Expansion Slots/~IRQ6: J303.8, U501.7 (GPB6)
/Expansion Slots/~IRQ7: J303.9, U501.8 (GPB7)
/Expansion Slots/~RESET: J301.4, J302.14 (~RESET), J304.14 (~RESET), J307.14 (~RESET), J308.14 (~RESET), R1308.1, U1301.8 (PA2)
/IO Expansion/CS_SEL0: R502.2, U501.21 (GPA0), U502.1 (A0)
/IO Expansion/CS_SEL1: R504.2, U501.22 (GPA1), U502.2 (A1)
/IO Expansion/CS_SEL2: R506.2, U501.23 (GPA2), U502.3 (A2)
/IO Expansion/E2: R511.1, U502.5 (E2)
/IO Expansion/E3: R510.2, U502.6 (E3)
/IO Expansion/SPI_CIPO: C501.1, R501.2
/IO Expansion/~LED0: R512.2, U501.24 (GPA3), U503.2
/IO Expansion/~LED1: D501.1 (K), U501.25 (GPA4)
/IO Expansion/~LED2: D502.1 (K), U501.26 (GPA5)
/IO Expansion/~LED3: D503.1 (K), U501.27 (GPA6)
/IO Expansion/~LED4: D504.1 (K), U501.28 (GPA7)
/IO Expansion/~OUTPUT_EN: R508.2, U502.4 (E1)
/Power Supply/PSU_CTRL: D402.1 (K), R405.1, U401.1 (Ctrl)
/Serial/RS232_CTS_IN: J701.8, J702.8, U701.8 (R2IN)
/Serial/RS232_RTS_OUT: J701.7, J702.7, U701.7 (T2OUT)
/Serial/RS232_RX_IN: J701.2, J702.2, U701.13 (R1IN)
/Serial/RS232_TX_OUT: J701.3, J702.3, U701.14 (T1OUT)
/USB/USBD1+: J901.2 (D-), U902.11 (D1+)
/USB/USBD1-: J901.3 (D+), U902.10 (D1-)
/USB/USBD2+: J901.6 (D-), U902.9 (D2+)
/USB/USBD2-: J901.7 (D+), U902.8 (D2-)
/USB/USBD3+: J902.2 (D-), U902.7 (D3+)
/USB/USBD3-: J902.3 (D+), U902.6 (D3-)
/USB/USBD4+: J902.6 (D-), U902.5 (D4+)
/USB/USBD4-: J902.7 (D+), U902.4 (D4-)
/USB/USB_3V3: C904.1, C905.1, R902.1, R903.1, R904.1, R905.1, U902.21 (VCC33)
/USB/USB_5V: C906.1, C907.1, U901.6 (OUT), U901.7 (OUT), U902.20 (VCC5), U903.1 (VIN), U904.1 (VIN), U905.1 (VIN), U906.1 (VIN)
/USB/~ENABLE: R901.2, U901.4 (~EN)
/Video/BLUE_ANA: R1209.1, R1210.1, U601.3 (CH3_IN)
/Video/DDC_SCL: JP603.1 (A), U602.11 (DDC_IN2)
/Video/DDC_SDA: JP604.1 (A), U602.10 (DDC_IN1)
/Video/GREEN_ANA: R1109.1, R1110.1, U601.2 (CH2_IN)
/Video/HSYNC: JP601.1 (A), U602.15 (SYNC_IN2)
/Video/RED_ANA: R1009.1, R1010.1, U601.1 (CH1_IN)
/Video/VGA_BLU: J601.3, R603.1, U602.3 (VIDEO1)
/Video/VGA_DDC_SCL: J601.15, JP603.2 (B), R606.2, U602.12 (DDC_OUT2)
/Video/VGA_DDC_SDA: J601.12, JP604.2 (B), R605.2, U602.9 (DDC_OUT1)
/Video/VGA_GRN: J601.2, R602.1, U602.4 (VIDEO2)
/Video/VGA_HSYNC_BUF: J601.13, JP601.2 (B), U602.16 (SYNC_OUT2)
/Video/VGA_RED: J601.1, R601.1, U602.5 (VIDEO3)
/Video/VGA_VSYNC_BUF: J601.14, JP602.2 (B), U602.14 (SYNC_OUT1)
/Video/VSYNC: JP602.1 (A), U602.13 (SYNC_IN1)
GND: C201.2, C202.2, C203.1, C204.2, C205.2, C206.2, C207.2, C208.2, C209.2, C216.1, C217.1, C219.1, C301.2, C302.2, C303.2, C304.2, C305.2, C306.2, C401.2, C402.2, C403.2, C404.1, C405.1, C406.2, C407.2, C501.2, C502.2, C503.2, C601.2, C602.1, C603.1, C604.1, C605.1, C701.1, C704.1, C705.1, C801.2, C802.2, C803.2, C804.2, C805.2, C806.2, C807.2, C808.2, C809.2, C810.2, C811.2, C812.2, C901.2, C902.2, C903.2, C904.2, C905.2, C906.2, C907.2, C908.2, C909.2, C910.2, C911.2, C1301.1, C1302.1, C1303.2, C1304.1, C1401.1, D402.2 (A), H101.1, H102.1, H103.1, H104.1, H105.1, H106.1, H107.1, H108.1, H109.1, J201.2, J201.3, J202.2, J202.4, J203.2, J203.3, J301.1, J302.2 (GND), J302.4 (GND), J302.6 (GND), J302.19 (GND), J302.20 (GND), J303.1, J304.2 (GND), J304.4 (GND), J304.6 (GND), J304.19 (GND), J304.20 (GND), J305.1, J306.1, J307.2 (GND), J307.4 (GND), J307.6 (GND), J307.19 (GND), J307.20 (GND), J308.2 (GND), J308.4 (GND), J308.6 (GND), J308.19 (GND), J308.20 (GND), J401.2, J402.1, J402.2, J403.2, J403.3, J601.5, J601.6, J601.7, J601.8, J601.10, J701.5, J702.5, J801.L2 (LEDY_K), J801.L3 (LEDG_K), J801.R8 (GND), J901.4 (GND), J901.8 (GND), J901.9 (Shield), J902.4 (GND), J902.8 (GND), J902.9 (Shield), J1301.3, J1301.9, J1302.2, J1303.2, J1305.1, J1401.3 (VSS), J1401.6 (VSS), J1401.12 (SHELL1), J1401.13 (SHELL2), NT301.2, NT303.2, NT306.2, NT307.2, NT308.2, NT311.2, Q401.2 (E), Q1301.2 (E), Q1302.2 (S), Q1303.2 (S), R201.1, R202.1, R205.2, R206.2, R207.2, R208.1, R209.1, R210.1, R403.2, R404.2, R511.2, R604.1, R701.2, R802.2, R812.2, R906.2, R907.2, R1002.2, R1010.2, R1102.2, R1110.2, R1202.2, R1210.2, R1305.2, R1308.2, R1309.2, R1312.2, R1315.2, R1319.2, SW1301.1, SW1302.1, U101.2.10 (GND), U101.2.11 (GND), U101.2.12 (GND), U101.3.7 (GND), U101.3.8 (GND), U101.3.9 (GND), U201.11 (HPGND), U201.15 (AGND), U201.28 (DGND), U202.1 (Sleeve), U401.3 (GND), U402.1 (GND), U403.1 (GND), U501.10 (VSS), U501.15 (A0), U501.16 (A1), U501.17 (A2), U502.8 (GND), U503.3 (GND), U601.5 (GND), U602.6 (GND), U701.15 (GND), U801.1 (VSSOSC), U801.13 (VSSPLL), U801.14 (VSSRX), U801.19 (VSSTX), U801.22 (VSSTX), U801.33 (VSS), U801.42 (VSS), U901.1 (GND), U902.1 (GND), U903.2 (GND), U904.2 (GND), U905.2 (GND), U906.2 (GND), U1301.16 (VSS), U1301.32 (VSS), Y201.2, Y201.4
unnamed: C203.2, U201.26 (XTO), Y201.3
unnamed: C204.1, U201.25 (XTI/MCK), Y201.1
unnamed: C214.1, C217.2, R210.2, R211.2
unnamed: C215.1, C216.2, R207.1, R212.2
unnamed: C218.2, R204.2
unnamed: C401.1, D401.1 (K), L401.1, Q402.2 (S), TP401.1
unnamed: C602.2, U602.8 (BYP)
unnamed: C702.1, U701.3 (C1-)
unnamed: C702.2, U701.1 (C1+)
unnamed: C703.1, U701.4 (C2+)
unnamed: C703.2, U701.5 (C2-)
unnamed: C704.2, U701.2 (VS+)
unnamed: C705.2, U701.6 (VS-)
unnamed: C808.1, U801.43 (VCAP)
unnamed: C809.1, R803.2, Y801.1
unnamed: C810.1, U801.3 (OSC1), Y801.2
unnamed: C811.1, J801.R4 (TCT), R808.2
unnamed: C812.1, J801.R5 (RCT), R809.2
unnamed: C901.1, U902.2 (XTALOUT), Y901.2
unnamed: C903.1, U902.3 (XTALIN), Y901.1
unnamed: C908.1, J901.1 (VBUS), U903.5 (VOUT)
unnamed: C909.1, J901.5 (VBUS), U904.5 (VOUT)
unnamed: C910.1, J902.1 (VBUS), U905.5 (VOUT)
unnamed: C911.1, J902.5 (VBUS), U906.5 (VOUT)
unnamed: D401.2 (A), Q402.1 (G), R403.1
unnamed: D501.2 (A), R503.2
unnamed: D502.2 (A), R505.2
unnamed: D503.2 (A), R507.2
unnamed: D504.2 (A), R509.2
unnamed: D1301.1 (K), R1309.1
unnamed: D1302.1 (K), R1312.1
unnamed: F401.1, Q402.3 (D)
unnamed: F401.2, J401.1, J402.3, J402.4
unnamed: J302.11 (EEPROM_ADDR0), NT301.1
unnamed: J302.12 (EEPROM_ADDR1), NT302.1
unnamed: J302.13 (EEPROM_ADDR2), NT303.1
unnamed: J304.11 (EEPROM_ADDR0), NT304.1
unnamed: J304.12 (EEPROM_ADDR1), NT305.1
unnamed: J304.13 (EEPROM_ADDR2), NT306.1
unnamed: J307.11 (EEPROM_ADDR0), NT307.1
unnamed: J307.12 (EEPROM_ADDR1), NT308.1
unnamed: J307.13 (EEPROM_ADDR2), NT309.1
unnamed: J308.11 (EEPROM_ADDR0), NT310.1
unnamed: J308.12 (EEPROM_ADDR1), NT311.1
unnamed: J308.13 (EEPROM_ADDR2), NT312.1
unnamed: J601.0, R604.2
unnamed: J702.0 (PAD), R701.1
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

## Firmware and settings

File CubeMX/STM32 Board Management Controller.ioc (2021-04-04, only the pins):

Mcu.UserName=STM32F030K6Tx
PA14.GPIO_Label=SWD_CLK
PA0.GPIO_Label=MON_3V3
PA6.GPIO_Label=SPI_CIPO
PB0.GPIO_Label=LED0
PB6.GPIO_Label=I2C_SCL
PA15.GPIO_Label=PS2_CLK0
PA12.Signal=USART1_RTS
PB6.Signal=I2C1_SCL
PF0-OSC_IN.GPIO_Label=nBUTTON_PWR
PB1.GPIO_Label=LED1
PA10.GPIO_Label=UART_RX
PB7.Signal=I2C1_SDA
PA8.Signal=GPIO_Output
PA0.Signal=ADC_IN0
PB7.GPIO_Label=I2C_SDA
PB1.Signal=S_TIM3_CH4
PA6.Signal=SPI1_MISO
PA2.GPIO_Label=nSYS_RESET
PA10.Signal=USART1_RX
PA15.Signal=GPXTI15
PB5.GPIO_Label=PS2_DAT1
PA4.GPIO_Label=nSPI_CS
PF1-OSC_OUT.Signal=GPIO_Input
PB4.Signal=GPIO_Input
PA3.Signal=GPIO_Output
PB3.GPIO_Label=PS2_CLK1
PA9.GPIO_Label=UART_TX
PA11.GPIO_Label=UART_CTS
PA12.GPIO_Label=UART_RTS
PA13.Signal=SYS_SWDIO
PA8.GPIO_Label=nHOST_IRQ
PA9.Signal=USART1_TX
PA1.Signal=ADC_IN1
PA5.Signal=SPI1_SCK
PB4.GPIO_Label=PS2_DAT0
PA1.GPIO_Label=MON_5V0
PF1-OSC_OUT.GPIO_Label=nBUTTON_RST
PA2.Signal=GPIO_Output
PA13.GPIO_Label=SWD_IO
PB3.Signal=GPXTI3
PA4.Signal=SPI1_NSS
PB5.Signal=GPIO_Input
PA7.GPIO_Label=SPI_COPI
PA5.GPIO_Label=SLK_CLK
PA11.Signal=USART1_CTS
PA14.Signal=SYS_SWCLK
PF0-OSC_IN.Signal=GPIO_Input
PB0.Signal=S_TIM3_CH3
PA3.GPIO_Label=DC_ON
PA7.Signal=SPI1_MOSI

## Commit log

2020-12-05 Adding a skeleton ATX board layout to demonstrate connector layout.
    [Neotron-Common-Hardware.kicad_pcb, Neotron-Common-Hardware.sch]
2020-12-13 Add some comments to the schematic.
    [Neotron-Common-Hardware.sch]
2020-12-13 Added 3D models for all edge connectors.
    Also moved down a directory to make it simpler.
    [039299246.stp, 61400826021.stp, KMDGX-6S-6S-S4N_rB8.STEP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]
2020-12-14 Update notes on schematic.
    [Neotron-Common-Hardware.sch]
2020-12-17 Fixing up hole locations on the PCB.
    [Neotron-Common-Hardware.kicad_pcb]
2020-12-20 Splitting into sub-modules.
    Also started Audio jack connections.
    [Neotron-Common-Hardware.sch, audio.sch, ethernet.sch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]
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2020-12-20 Need to touch an sch to get it to build.
    [joysticks.sch]
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2020-12-20 Brought in RS232 circuit from Neotron 32.
    Also updated 3D models.
    [Neotron-Common-Hardware.kicad_pcb, Neotron-Common-Hardware.sch, audio.sch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]
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2020-12-22 Tidied up Audio page.
    [audio.sch]
2020-12-22 Updating BOM with parts.
    [ethernet.sch, joysticks.sch, powersupply.sch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]
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2020-12-22 Wired up Ethernet sheet.
    [Neotron-Common-Hardware.sch, ethernet.sch]
2020-12-22 Gave sheets unique titles
    [joysticks.sch, powersupply.sch, ps2.sch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]
2020-12-22 Add ATX/ITX mounting holes.
    [Neotron-Common-Hardware.kicad_pcb, Neotron-Common-Hardware.sch, ethernet.sch]
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2020-12-23 Added dual Type-A USB header.
    [Neotron-Common-Hardware.kicad_pcb, usb.sch]
2020-12-24 Working on VGA sheet and USB sheet.
    Also added courtyard and silk to stacked USB connector.
    [Neotron-Common-Hardware.kicad_pcb, Neotron-Common-Hardware.sch, usb.sch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]
2020-12-25 Set revision to [Uncontrolled]
    [Neotron-Common-Hardware.sch, audio.sch, joysticks.sch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]
2020-12-25 Fix up ERC errors.
    ~FAULT on the MIC2005 is an active-low common collector output.
    Well done ERC for spotting that I can't join three output pins together!
    [Neotron-Common-Hardware.sch, ethernet.sch, usb.sch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]
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2020-12-25 Add master USB power switch.
    [Neotron-Common-Hardware.sch]
2020-12-25 Added empty SD card sheet.
    [Neotron-Common-Hardware.sch, audio.sch, ethernet.sch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]
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2020-12-26 Added SD card sheet.
    Simple setup - 10k pullups, no ESD protection.
    [Neotron-Common-Hardware.sch, sdcard.sch]
2020-12-26 Fix V+ capacitor - must go to ground, not Vcc.
    [serial.sch]
2020-12-26 Completed PSU design.
    Also changed footprint for stacked USB connector to change
    shield pins from SHx to Pin 9.
    [Neotron-Common-Hardware.kicad_pcb, Neotron-Common-Hardware.sch, audio.sch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]
2020-12-27 Replaced NUC029 (TSSOP) with KE04 (SOIC).
    Also updated the BOM with some part nos.
    [Neotron-Common-Hardware.kicad_pcb, Neotron-Common-Hardware.sch, audio.sch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]
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2020-12-29 Video sheet takes digital video, not analog video.
    DAC is TBD.
    [video.sch]
2020-12-29 Make CPU card bigger.
    Just big enough to take a TQFP-176 now.
    [Neotron-Common-Hardware.kicad_pcb, Neotron-Common-Hardware.sch, audio.sch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]
2020-12-30 Revised CPU connector to be two 2x20.
    This gives more room for larger TQFP-176+ CPUs to be fitted that
    didn't fit on the PGA-80 design.
    [Neotron-Common-Hardware.kicad_pcb, Neotron-Common-Hardware.sch, audio.sch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]
2020-12-30 Changed CPU socket to be 2x20 x2. Added expansion slots.
    Also added 3D model for the SD card.
    [145638009211859+--3DModel-STEP-56544.STEP, 5-5530843-0--3DModel-STEP-1.STEP, Neotron-Common-Hardware.kicad_pcb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]
2020-12-31 Rejigged expansion socket, and added pinout to README.
    [Neotron-Common-Hardware.kicad_pcb, Neotron-Common-Hardware.sch]
2021-01-01 Add real-time clock.
    I copied the MCP7940N design from the Neotron-32 but changed
    the chip to a SOIC-8.
    [Neotron-Common-Hardware.kicad_pcb, Neotron-Common-Hardware.sch, audio.sch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]
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2021-01-01 Remove old "mpn" field on components.
    Use "MPN" instead.
    [audio.sch, rtc.sch, serial.sch]
2021-01-01 Fix ERC error when CIPO pins joined together.
    Tristate the CIPO pin on an expansion slot, and on the Ethernet chip.
    [Neotron-Common-Hardware.sch, audio.sch, ethernet.sch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]
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2021-01-06 Replaced KE04Z with STM32F0.
    Had trouble debugging a test KE06Z device. Decided an STM32 would be simpler.
    [dac.sch, powersupply.sch]
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2021-01-07 Update README.md
    Added arrows to CPU header diagram
    Added suggestions for future expansion cards
    Specified EEPROM addresses for each slot
    Clarified types of regulator used
    Noted that BMC runs from standby regulator
    Note that internal line-in doesn't work if external line-in used (but line-output does work if headphone out is used)
2021-01-07 Swap pinout on CPU connector to better match SDMMC connector.
2021-01-08 Switch to 8 pin debug header (J902)
    Closes #15
    [powersupply.sch]
2021-01-08 K7805-3AR3 updates:
    ) Add footprint with courtyard.
    ) Note that several of the pins are duplicated, not independent.
    ) Add aliases for other voltage variants.
    ) Tidy up schematic back on to the 50 mil grid.
    [powersupply.sch]
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2021-01-08 Replace inductor with horizontal footprint.
    [Neotron-Common-Hardware.kicad_pcb, powersupply.sch]
2021-01-08 Update CHANGELOG with release.
    Also fix typo in README about input voltage range.
2021-01-16 Switch some of the radial THT Electrolytic caps for SMD MLCCs.
    Also changed the STM32 for an LQFP-32 as it has a bigger pitch on the
    pins.
    The LQFP is easier to solder than the TSSOP, and the MLCC takes are
    cheaper and take up less space.
    [Neotron-Common-Hardware.kicad_pcb, Neotron-Common-Hardware.sch, audio.sch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]
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2021-03-29 README updates.
    Correct part number for STM32 BMC.
    Added footprints to README, and other details.
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2021-04-02 Added 12-bit video DAC.
    Also had to change footprints to suit Kicad 5.1.9
    [Neotron-Common-Hardware.kicad_pcb, Neotron-Common-Hardware.sch, audio.sch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]
2021-04-02 Add 4-bit Video DAC, and re-wire BMC.
    Now the BMC is an SPI device, and has a four-wire UART.
    [Neotron-Common-Hardware.sch, audio.sch, dac4.sch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]
2021-04-02 Tidy up part nos and swapped I2C/UART on BMC.
    Mark all resistors as 1% if not specified.
    Added some Mouser part numbers.
    BMC can now be programmed over UART.
    [Neotron-Common-Hardware.sch, audio.sch, dac4.sch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]
2021-04-04 Changes to BMC
    * Swapped BUTTON_PWR and SYS_RESET to avoid DRC issue
    * Split PSU and BMC into two separate sheets
    * Swapped some pins on the STM32 to make it compatible with more
    alternatives
    [Neotron-Common-Hardware.kicad_pcb, Neotron-Common-Hardware.sch, audio.sch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]
2021-04-04 Set LR and BCLK on Audio.sch to be bi-directional
    In Controller mode these pins are outputs. In peripheral
    mode these pins are inputs.
    [Neotron-Common-Hardware.sch, audio.sch]
2021-04-05 Join GNDA and GND on audio sheet.
    Most guides recommend against having a split ground, and it certainly
    makes layout harder.
    [audio.sch]
2021-04-06 Revised PSU switch-on circuit.
    Updated notes on BMC and Audio sheet.
    [Neotron-Common-Hardware.sch, audio.sch, bmc.sch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]
2021-04-06 Fix spaces in MPNs.
    [audio.sch]
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2021-06-18 Brought in sheets from Neotron Pico.
    Also includes DB15HD and PSU 3D models.
    [ICD15S13E4GV00LFc.stp, K78XX-3AR3.step, Neotron-Common-Hardware.kicad_pcb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]
2021-06-18 Merge in more changes.
    Mostly lowering voltage tolerances to minimum required.
    [Neotron-Common-Hardware.sch, audio.sch, bmc.sch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]
2021-06-18 Fixups after last copy-over.
    [Neotron-Common-Hardware.kicad_pcb, io_exp.sch, video12.sch]
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2021-08-07 Add second variant of TPF133a with pins swapped around.
    Might make PCB layout easier. Channels are interchangeble.
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2022-12-24 Update schematic files to Kicad 6.
    Had to fix some symbols which didn't have perfect matches in K6.
    [Neotron-Common-Hardware.kicad_sch, Neotron-Common-Hardware.sch, audio.kicad_sch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]
2022-12-24 Fixup PCB.
    We don't run DRC as the PCB isn't routed.
    [Neotron-Common-Hardware.kicad_pcb]
2022-12-24 Imported sheets from Neotron Pico.
    Standardised on +3V3 not +3.3V
    [Neotron-Common-Hardware.kicad_sch, audio.kicad_sch, bmc.kicad_sch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]
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2022-12-24 Set missing footprints and update PCB
    [Neotron-Common-Hardware.kicad_pcb, Neotron-Common-Hardware.kicad_sch, audio.kicad_sch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]
2022-12-26 Re-imported from Neotron Pico v1.1.
    This time I deleted the sheets from the top level and then re-added pointing at the new files. I also reset the PCB dimensions to match the Neotron Pico.
    This seems to have done a better job importing footprints.
    [Neotron-Common-Hardware.kicad_pcb, Neotron-Common-Hardware.kicad_sch, audio.kicad_sch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]
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

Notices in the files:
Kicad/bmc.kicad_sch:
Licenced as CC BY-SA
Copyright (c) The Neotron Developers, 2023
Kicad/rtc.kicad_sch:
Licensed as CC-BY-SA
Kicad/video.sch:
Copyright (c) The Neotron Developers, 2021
